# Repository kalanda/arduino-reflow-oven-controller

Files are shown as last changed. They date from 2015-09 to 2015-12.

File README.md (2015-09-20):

# Arduino Reflow Oven Controller

This is my custom design of an Arduino Reflow Oven Controller for reflow soldering of SMD components. 

Using a thermocouple to know the temperature inside the oven, this device controls a regular food oven using a SSR(Solid State Relay) for turning the power ON and OFF in order to get the desired temperature on each time to adjust it to the reflow profile. Is possible to choose between leaded and lead-free reflow profiles. The oven was previously modified to take out the thermostat and the timer to make possible to reach higher temperatures. 

The main hardware parts are:

- Arduino Mini
- K type thermocouple
- MAX31855 thermocouple amplifier (breakout from Adafruit) 
- SSR (Solid State Relay) 24-240VAC - 10A 
- LCD Display 16x2
- A couple of buttons and one led
- Some others components like cables, power connectors, power supply, etc...

All the EagleCad files and the Arduino firmware code are available at this repository. 

## Schema

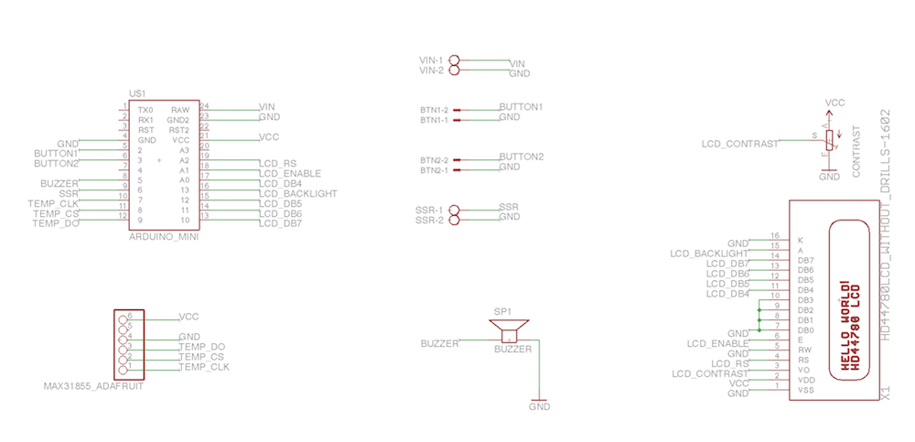
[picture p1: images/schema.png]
Schema


## License

The MIT License (MIT)

Copyright (c) 2015 kalanda

Permission is hereby granted, free of charge, to any person obtaining a copy
of this software and associated documentation files (the "Software"), to deal
in the Software without restriction, including without limitation the rights
to use, copy, modify, merge, publish, distribute, sublicense, and/or sell
copies of the Software, and to permit persons to whom the Software is
furnished to do so, subject to the following conditions:

The above copyright notice and this permission notice shall be included in all
copies or substantial portions of the Software.

THE SOFTWARE IS PROVIDED "AS IS", WITHOUT WARRANTY OF ANY KIND, EXPRESS OR
IMPLIED, INCLUDING BUT NOT LIMITED TO THE WARRANTIES OF MERCHANTABILITY,
FITNESS FOR A PARTICULAR PURPOSE AND NONINFRINGEMENT. IN NO EVENT SHALL THE
AUTHORS OR COPYRIGHT HOLDERS BE LIABLE FOR ANY CLAIM, DAMAGES OR OTHER
LIABILITY, WHETHER IN AN ACTION OF CONTRACT, TORT OR OTHERWISE, ARISING FROM,
OUT OF OR IN CONNECTION WITH THE SOFTWARE OR THE USE OR OTHER DEALINGS IN THE
SOFTWARE.

## Some photos

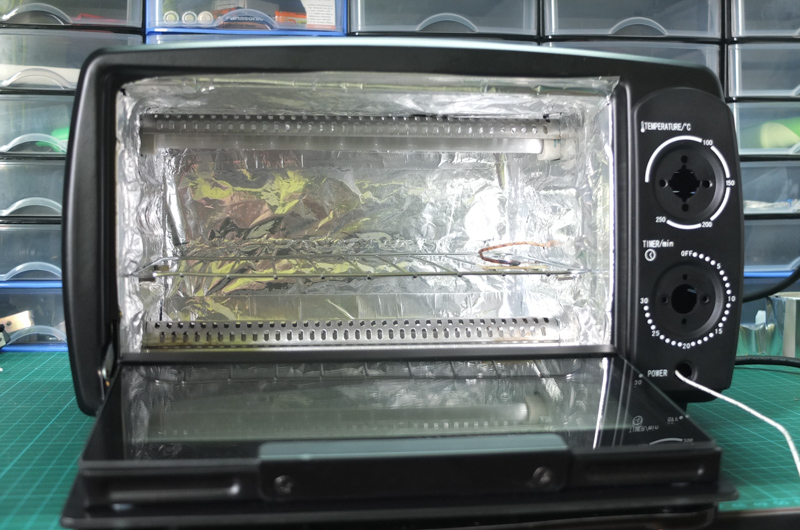
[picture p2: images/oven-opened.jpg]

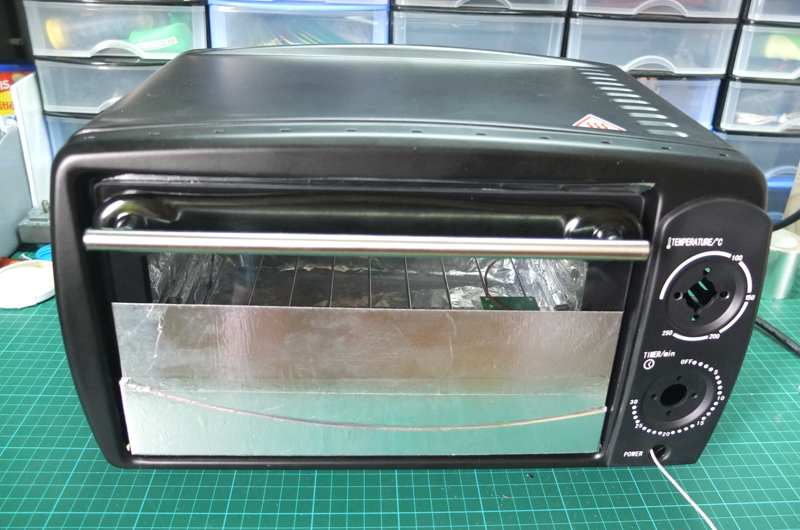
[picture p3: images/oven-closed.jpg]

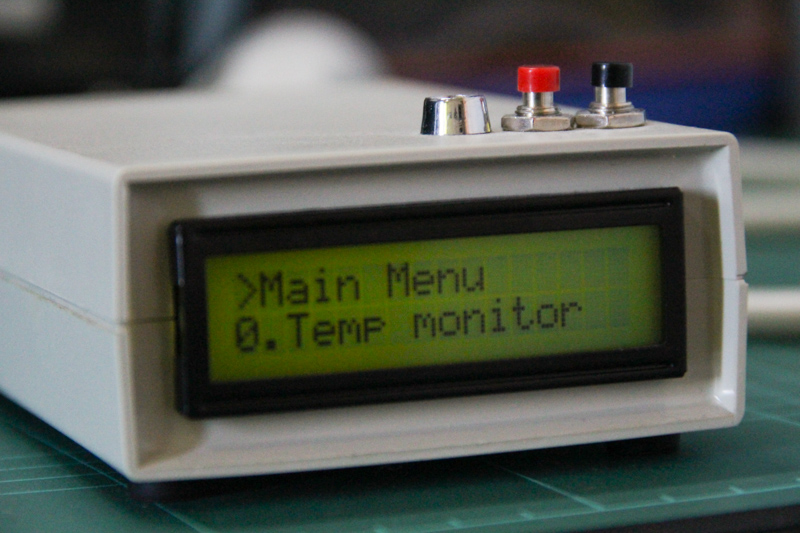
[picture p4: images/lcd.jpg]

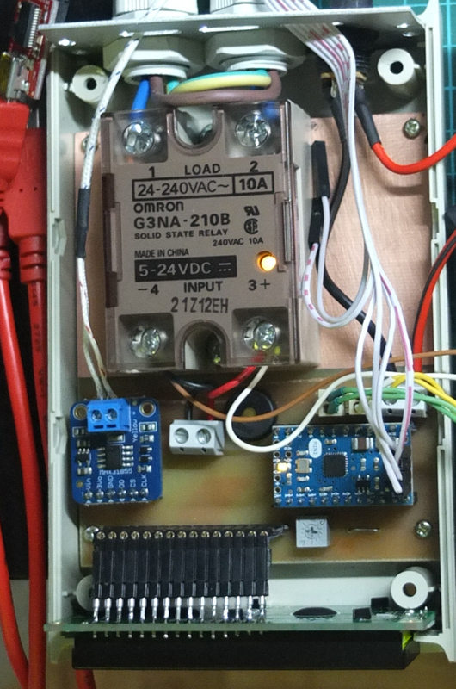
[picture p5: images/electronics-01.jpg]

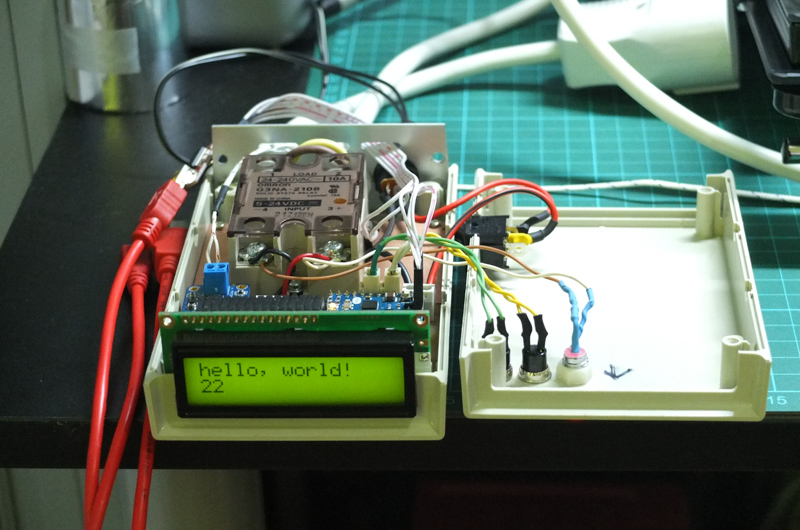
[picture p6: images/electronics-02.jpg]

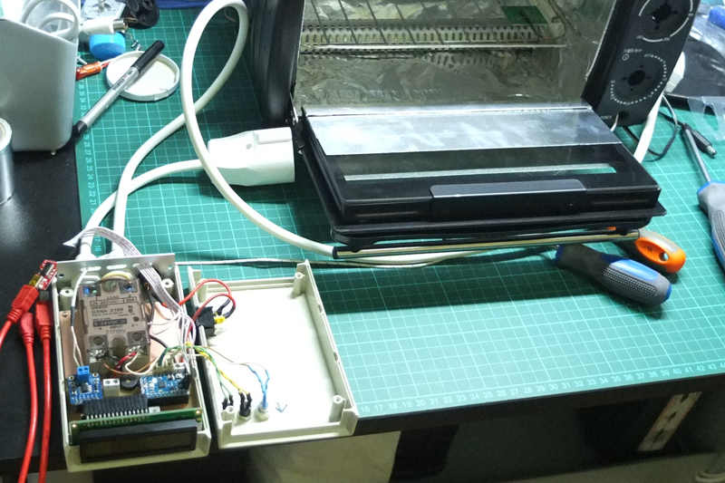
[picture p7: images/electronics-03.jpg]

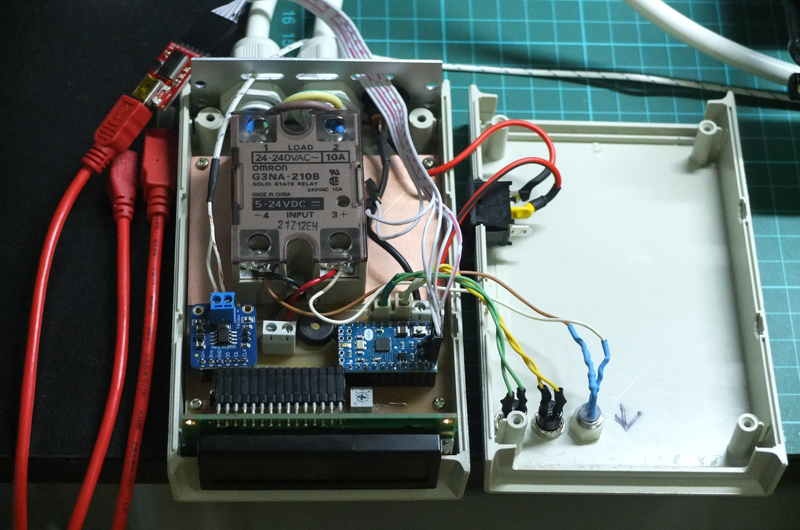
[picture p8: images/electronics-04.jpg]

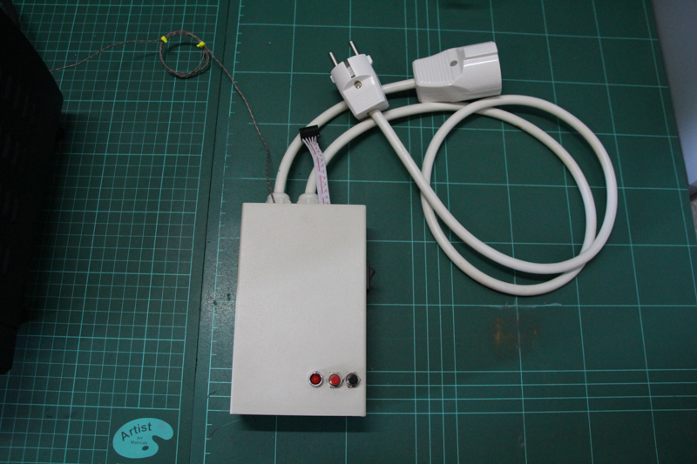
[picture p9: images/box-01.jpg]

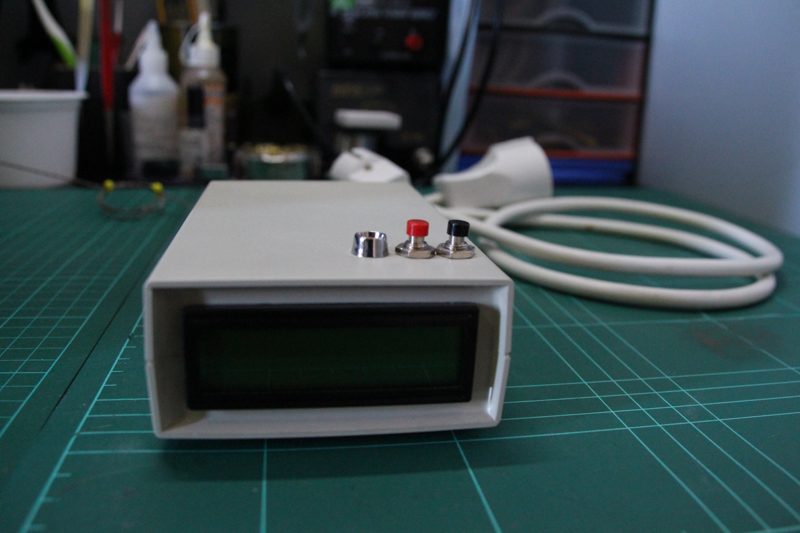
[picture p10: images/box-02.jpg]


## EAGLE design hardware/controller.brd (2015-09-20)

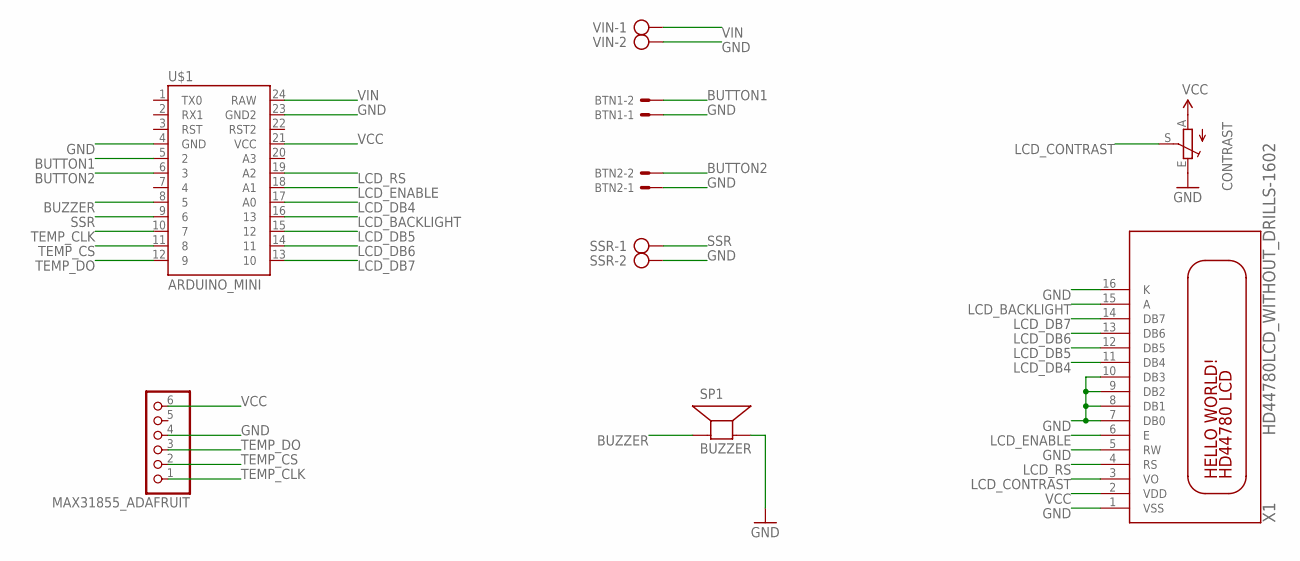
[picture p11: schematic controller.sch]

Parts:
BTN1, BTN2: 22-27-2021-02; 6410-02
CONTRAST: TRIM_EU-B25U; B25U
MAX31855_ADAFRUIT: PINHD-1X6; 1X06
SP1: BUZZER; PS12
SSR: AK500/2
U$1: ARDUINO_MINI
VIN: AK500/2
X1: HD44780LCD_WITHOUT_DRILLS-1602; LCD1602

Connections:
BUTTON1: BTN1.2, U$1.5 (2)
BUTTON2: BTN2.2, U$1.6 (3)
BUZZER: SP1.P$1 (+), U$1.8 (5)
GND: BTN1.1, BTN2.1, CONTRAST.E, MAX31855_ADAFRUIT.4, SP1.P$2 (-), SSR.2, U$1.4 (GND), U$1.23 (GND2), VIN.2, X1.1 (VSS), X1.5 (RW), X1.7 (DB0), X1.8 (DB1), X1.9 (DB2), X1.10 (DB3), X1.16 (K)
LCD_BACKLIGHT: U$1.16 (13), X1.15 (A)
LCD_CONTRAST: CONTRAST.S, X1.3 (VO)
LCD_DB4: U$1.17 (A0), X1.11 (DB4)
LCD_DB5: U$1.15 (12), X1.12 (DB5)
LCD_DB6: U$1.14 (11), X1.13 (DB6)
LCD_DB7: U$1.13 (10), X1.14 (DB7)
LCD_ENABLE: U$1.18 (A1), X1.6 (E)
LCD_RS: U$1.19 (A2), X1.4 (RS)
SSR: SSR.1, U$1.9 (6)
TEMP_CLK: MAX31855_ADAFRUIT.1, U$1.10 (7)
TEMP_CS: MAX31855_ADAFRUIT.2, U$1.11 (8)
TEMP_DO: MAX31855_ADAFRUIT.3, U$1.12 (9)
VCC: CONTRAST.A, MAX31855_ADAFRUIT.6, U$1.21 (VCC), X1.2 (VDD)
VIN: U$1.24 (RAW), VIN.1

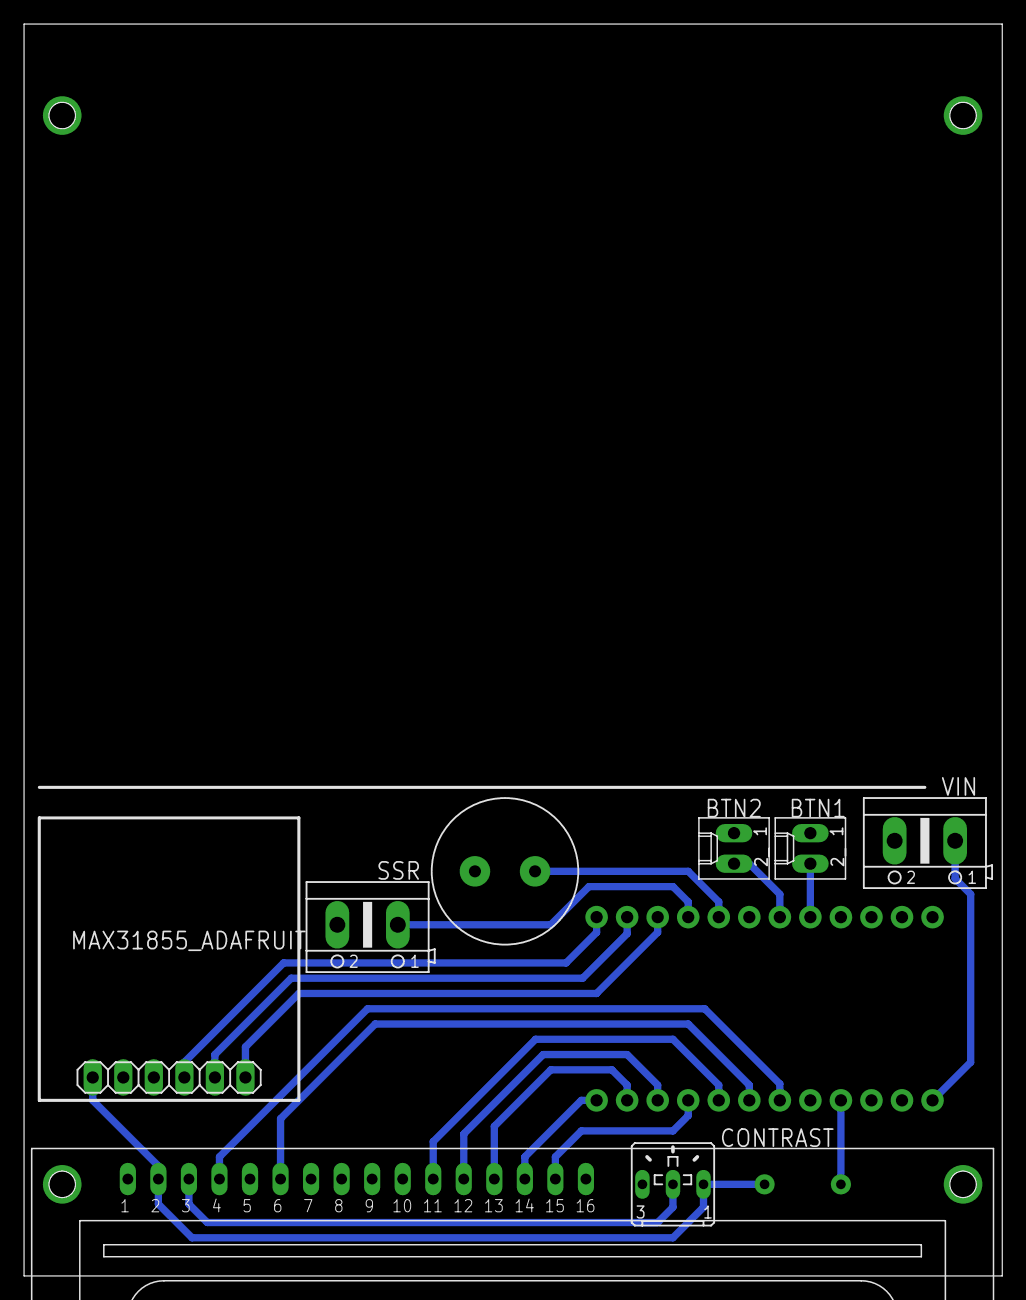
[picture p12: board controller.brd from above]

Board: 2 copper layers, 81.4 x 104.1 mm, 9 parts (0 on the bottom side), 18 nets.

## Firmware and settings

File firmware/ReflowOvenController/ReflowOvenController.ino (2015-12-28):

// Import libraries
#include <LiquidCrystal.h>
#include "FlexiTimer2_local.h"
#include "PID_v1_local.h"
#include "MAX31855_local.h"

// Version
#define CODE_MAJOR_VERSION     1  // major version
#define CODE_MINOR_VERSION     0  // minor version

// LCD settings
#define LCD_COLS              16  // columns
#define LCD_ROWS               2  // rows

// Pin settings
#define PINS_SSR               6
#define PINS_TEMP_SO           9
#define PINS_TEMP_CS           8
#define PINS_TEMP_CLK          7
#define PINS_LCD_LED           13
#define PINS_LCD_RS            A2
#define PINS_LCD_ENABLE        A1
#define PINS_LCD_D4            A0
#define PINS_LCD_D5            12
#define PINS_LCD_D6            11
#define PINS_LCD_D7            10
#define PINS_BUZZER            5
#define PINS_BTN_A             2
#define PINS_BTN_B             3

// Custom characters and symbols addresses at lcd eeprom
#define SYMBOL_DEGREE         0x00 // Degree

// Keycodes
#define KEY_NONE             0 // No keys pressed
#define KEY_A                1 // Button A was pressed
#define KEY_B                2 // Button B was pressed
#define KEY_AH               3 // Button A was pressed and holded (KEY_HOLD_TIME) milisecons
#define KEY_BH               4 // Button B was pressed and holded (KEY_HOLD_TIME) milisecons
#define KEY_ABH              5 // Buttons A+B was pressed and holded (KEY_HOLD_TIME) milisecons

// Keyboard times
#define KEY_DEBOUNCE_TIME    30 // debounce time (ms) to prevent flickering when pressing or releasing the button
#define KEY_HOLD_TIME       400 // holding period (ms) how long to wait for press+hold event
#define KEY_HOLD_TIME_WAIT  100 // Used for double key holding

// PID values
#define PID_SAMPLE_TIME    1000     // Milliseconds
#define PID_KP_PREHEAT      100.000
#define PID_KI_PREHEAT        0.025
#define PID_KD_PREHEAT       20.000
#define PID_KP_SOAK         300.000
#define PID_KI_SOAK           0.050
#define PID_KD_SOAK         250.000
#define PID_KP_REFLOW       300.000
#define PID_KI_REFLOW         0.050
#define PID_KD_REFLOW       350.000

// Minimun temperature to start a profile
#define ROOM_TEMPERATURE          40

#define REFLOW_PROFILE_LEADED      0
#define REFLOW_PROFILE_LEADFREE    1

#define REFLOW_STAGE_PREHEAT       0
#define REFLOW_STAGE_SOAK          1
#define REFLOW_STAGE_REFLOW        2
#define REFLOW_STAGE_COOL          3

// Struct to hold the reflow stage parameters.
typedef struct ReflowStage {
  const char* name;
  double targetTemperature;
  int durationInSeconds;
  int elapsedTime;
  double pid_kp;
  double pid_ki;
  double pid_kd;
} ReflowStage_t;

// Array to hold the individual reflow stages together as a complete reflow profile
ReflowStage currentReflowProfile[5];

// PID variables
double pid_setPoint;
double pid_input;
double pid_output;
double pid_kp = PID_KP_PREHEAT;
double pid_ki = PID_KI_PREHEAT;
double pid_kd = PID_KD_PREHEAT;

// Specify PID control interface
PID reflowOvenPID(&pid_input, &pid_output, &pid_setPoint, pid_kp, pid_ki, pid_kd, DIRECT);

// Thermocouple object instance
MAX31855 thermocouple(PINS_TEMP_SO, PINS_TEMP_CS, PINS_TEMP_CLK);

// LiquidCrystal LCD control object instance
LiquidCrystal lcd(PINS_LCD_RS, PINS_LCD_ENABLE, PINS_LCD_D4, PINS_LCD_D5, PINS_LCD_D6, PINS_LCD_D7);

// Variables used on interrupt mode
volatile boolean cancelFlag = false;    // Flag used to abort interrupt mode

// Global variables
uint8_t lastKey = KEY_NONE;     // Last key pressed
boolean flagHoldKey = false;    // Flag to ignore keys after a hold key
int currentStage = 0;
int timerSeconds = 0;

// Setup before start
void setup()
{
  // Create custom LCD char for degree symbol
  uint8_t char_degree[8]  = {
      B01100,
      B10010,
      B10010,
      B01100,
      B00000,
      B00000,
      B00000,
      B00000
  };

  // Initialize LCD
  lcd.begin( LCD_COLS,  LCD_ROWS);
  lcd.createChar(SYMBOL_DEGREE, char_degree);

  // Pinmode inputs
  pinMode(PINS_BTN_A, INPUT_PULLUP);
  pinMode(PINS_BTN_B, INPUT_PULLUP);

  // Pinmode outputs
  pinMode(PINS_LCD_LED,     OUTPUT);
  pinMode(PINS_LCD_RS,      OUTPUT);
  pinMode(PINS_LCD_ENABLE,  OUTPUT);
  pinMode(PINS_LCD_D4,      OUTPUT);
  pinMode(PINS_LCD_D5,      OUTPUT);
  pinMode(PINS_LCD_D6,      OUTPUT);
  pinMode(PINS_LCD_D7,      OUTPUT);
  pinMode(PINS_BUZZER,      OUTPUT);

  // Turn on lcd backlight
  digitalWrite(PINS_LCD_LED, HIGH);

  // Tell the PID to range between 0 and 255 (PWM Output)
  reflowOvenPID.SetOutputLimits(0, 255);

  // Turn the PID on
  reflowOvenPID.SetMode(AUTOMATIC);
  reflowOvenPID.SetSampleTime(PID_SAMPLE_TIME);

  // Put SSR to 0 duty
  analogWrite(PINS_SSR, 0);

  // Init serial
  Serial.begin(9600);
}

// Main loop
void loop()
{
  controller_run();
}

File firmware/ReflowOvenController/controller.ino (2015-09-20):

// Runs the controller
void controller_run()
{
   controller_showMainMenu();
}

// Main Menu View
void controller_showMainMenu()
{
  byte currentOption = 0;

  for(boolean exit = false;!exit;)
  {
    display_printTitle(F("Main Menu"));

    if(currentOption==0) display_printEnumeration(0, F("Temp monitor"));
    if(currentOption==1) display_printEnumeration(1, F("Run profile"));

    keyboard_waitForAnyKey();

    if(lastKey==KEY_A) circularList_incrementBy(&currentOption, 0, 1, -1);
    if(lastKey==KEY_B) circularList_incrementBy(&currentOption, 0, 1, 1);
    if(lastKey==KEY_AH) exit = true;
    if(lastKey==KEY_BH)
    {
          if(currentOption==0) runAs_tempMonitor();
          if(currentOption==1) controller_showProfileMenu();
    }
  }
}

// Main Menu View
void controller_showProfileMenu()
{
  byte currentOption = 0;

  for(boolean exit = false;!exit;)
  {
    display_printTitle(F("Run profile"));

    if(currentOption==0) display_printEnumeration(0, F("Leaded"));
    if(currentOption==1) display_printEnumeration(1, F("Lead-free"));

    keyboard_waitForAnyKey();

    if(lastKey==KEY_A) circularList_incrementBy(&currentOption, 0, 1, -1);
    if(lastKey==KEY_B) circularList_incrementBy(&currentOption, 0, 1, 1);
    if(lastKey==KEY_AH) exit = true;
    if(lastKey==KEY_BH)
    {
          if(currentOption==0) runAs_profile(REFLOW_PROFILE_LEADED);
          if(currentOption==1) runAs_profile(REFLOW_PROFILE_LEADFREE);
    }
  }
}

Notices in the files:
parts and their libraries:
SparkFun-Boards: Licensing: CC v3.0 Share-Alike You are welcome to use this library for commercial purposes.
